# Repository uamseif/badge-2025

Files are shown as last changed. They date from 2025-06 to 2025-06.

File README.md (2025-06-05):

# 🛠️ C1b3rtr4cks Badge 2025

Este repositorio contiene el diseño y firmware de la **badge oficial del evento de ciberseguridad [Cibertracks](https://www.c1b3rtr4cks.es/)**. Este badge está compuesta por **tres placas PCB** ensambladas como un **sandwich**, cada una diseñada en **KiCad**. Además de su función identificativa, su forma permite utilizarla como **portatarjetas físico** para credenciales o tarjetas del evento.

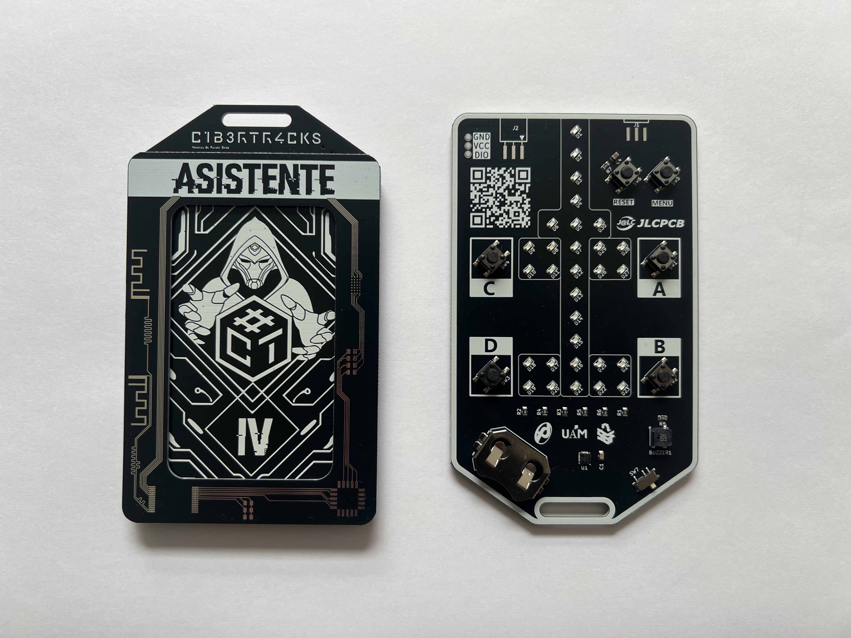
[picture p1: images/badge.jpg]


---

## 🧭 Descripción del Proyecto

- 🔧 **Diseño multicapa:** 3 placas PCB ensambladas en forma de sandwich.
- 🎨 **Diseño personalizado:** Adaptada para representar visualmente la identidad del evento.
- 💾 **Firmware en C:** Corre en un **CH32V003**, un microcontrolador RISC-V.
- 🪪 **Funcionalidad dual:** Badge electrónica + portatarjetas físico.

---

## 🧩 Hardware

La placa está diseñada en tres capas, cada una como un proyecto independiente en **KiCad**:

- **badge2025**: Capa frontal. Incluye LEDs, botones y detalles gráficos del evento.
- **middle_frame**: Elemento mecánico que actua como separador y de retenedor de tarjetas.
- **front_frame**: Capa frontal que extiende el diseño de la placa principal.

Estas capas se ensamblan de forma compacta, resultando en una badge robusta y funcional, apta para colgar con lanyard o sujetar una tarjeta del evento.

---

## 💻 Firmware

El firmware está ubicado en `software` y está desarrollado en **C** usando **PlatformIO**.

Se trata de una serie de minijuegos a los que se puede jugar con otra persona juntando dos placas. 

### 📦 Requisitos

- [PlatformIO](https://platformio.org/)
- Programador compatible con CH32V003 (ej. WCH-LinkE, USB-UART + BOOT0)

## ▶️ ¿Cómo usar la placa?

En la siguiente [página](HOW-TO-USE.md) encontramos instrucciones de como usar la placa y jugar con ella.

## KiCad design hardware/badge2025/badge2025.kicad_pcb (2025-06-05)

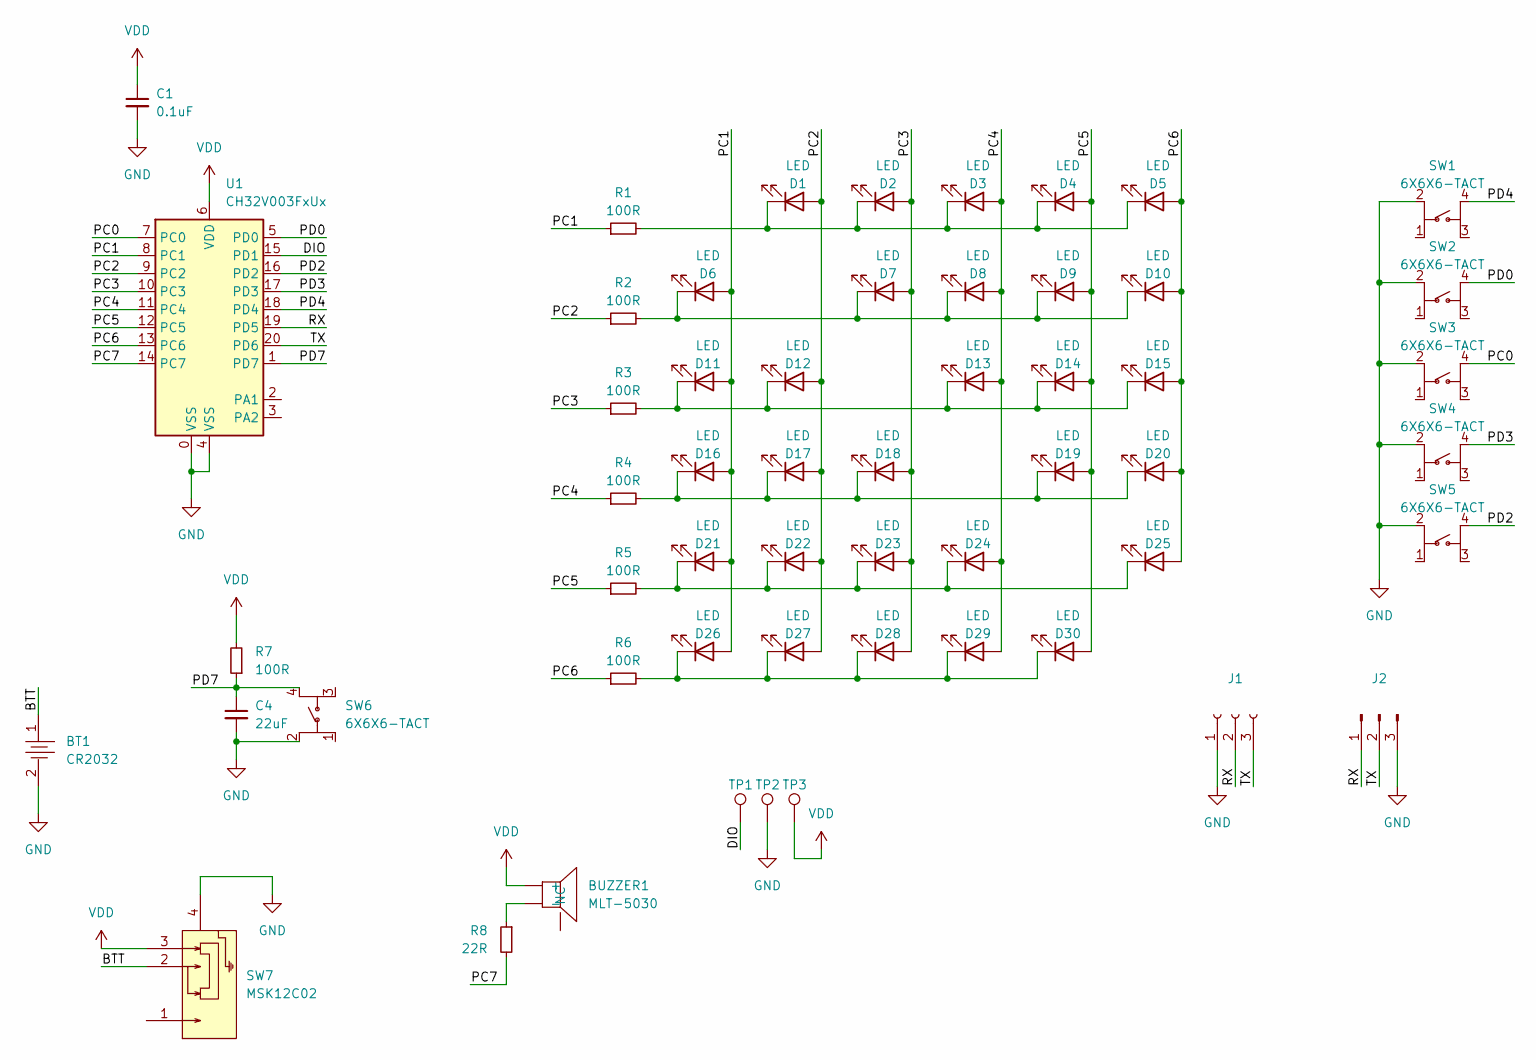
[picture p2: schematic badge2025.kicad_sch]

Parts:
BT1: CR2032; BAT-SMD_MY-2032-08
BUZZER1: MLT-5030; BUZ-SMD_3P-L5.2-W5.2-P3.50-BR
C1: 0.1uF; C_0805_2012Metric
C4: 22uF; C_0805_2012Metric
D1, D2, D3, D4, D5, D6, D7, D8, D9, D10, D11, D12, D13, D14, D15, D16, D17, D18, D19, D20, D21, D22, D23, D24, D25, D26, D27, D28, D29, D30: LED; LED_0805_2012Metric
J1: Conn_01x03_Socket; HDR-SMD_3P-P2.54-H-M
J2: Conn_01x03_Pin; HDR-SMD_3P-P2.54-H-F-L11.5
R1, R2, R3, R4, R5, R6, R7: 100R; R_0805_2012Metric
R8: 22R; R_0805_2012Metric
SW1, SW2, SW3, SW4, SW5, SW6: 6X6X6-TACT; SW-SMD_4P-L6.0-W6.0-P4.50-LS9.2
SW7: MSK12C02; SW-TH_MSK12C02
TP1, TP2, TP3: TestPoint; TestPoint_Pad_D1.5mm
U1: CH32V003FxUx; QFN-20-1EP_3x3mm_P0.4mm_EP1.65x1.65mm

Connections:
/BTT: BT1.1, SW7.2
/DIO: TP1.1, U1.15 (PD1)
/PC0: SW3.4 (D), U1.7 (PC0)
/PC1: D6.2 (A), D11.2 (A), D16.2 (A), D21.2 (A), D26.2 (A), R1.1, U1.8 (PC1)
/PC2: D1.2 (A), D12.2 (A), D17.2 (A), D22.2 (A), D27.2 (A), R2.1, U1.9 (PC2)
/PC3: D2.2 (A), D7.2 (A), D18.2 (A), D23.2 (A), D28.2 (A), R3.1, U1.10 (PC3)
/PC4: D3.2 (A), D8.2 (A), D13.2 (A), D24.2 (A), D29.2 (A), R4.1, U1.11 (PC4)
/PC5: D4.2 (A), D9.2 (A), D14.2 (A), D19.2 (A), D30.2 (A), R5.1, U1.12 (PC5)
/PC6: D5.2 (A), D10.2 (A), D15.2 (A), D20.2 (A), D25.2 (A), R6.1, U1.13 (PC6)
/PC7: R8.2, U1.14 (PC7)
/PD0: SW2.4 (D), U1.5 (PD0)
/PD2: SW5.4 (D), U1.16 (PD2)
/PD3: SW4.4 (D), U1.17 (PD3)
/PD4: SW1.4 (D), U1.18 (PD4)
/PD7: C4.1, R7.1, SW6.4 (D), U1.1 (PD7)
/RX: J1.2, J2.1, U1.19 (PD5)
/TX: J1.3, J2.2, U1.20 (PD6)
/XI: U1.2 (PA1)
/XO: U1.3 (PA2)
GND: BT1.2, C1.2, C4.2, J1.1, J2.3, SW1.2 (B), SW2.2 (B), SW3.2 (B), SW4.2 (B), SW5.2 (B), SW6.2 (B), SW7.4, TP2.1, U1.0 (VSS), U1.4 (VSS)
unnamed: BUZZER1.3 (-), R8.1
unnamed: D1.1 (K), D2.1 (K), D3.1 (K), D4.1 (K), D5.1 (K), R1.2
unnamed: D6.1 (K), D7.1 (K), D8.1 (K), D9.1 (K), D10.1 (K), R2.2
unnamed: D11.1 (K), D12.1 (K), D13.1 (K), D14.1 (K), D15.1 (K), R3.2
unnamed: D16.1 (K), D17.1 (K), D18.1 (K), D19.1 (K), D20.1 (K), R4.2
unnamed: D21.1 (K), D22.1 (K), D23.1 (K), D24.1 (K), D25.1 (K), R5.2
unnamed: D26.1 (K), D27.1 (K), D28.1 (K), D29.1 (K), D30.1 (K), R6.2
VDD: BUZZER1.2 (+), C1.1, R7.2, SW7.3, TP3.1, U1.6 (VDD)

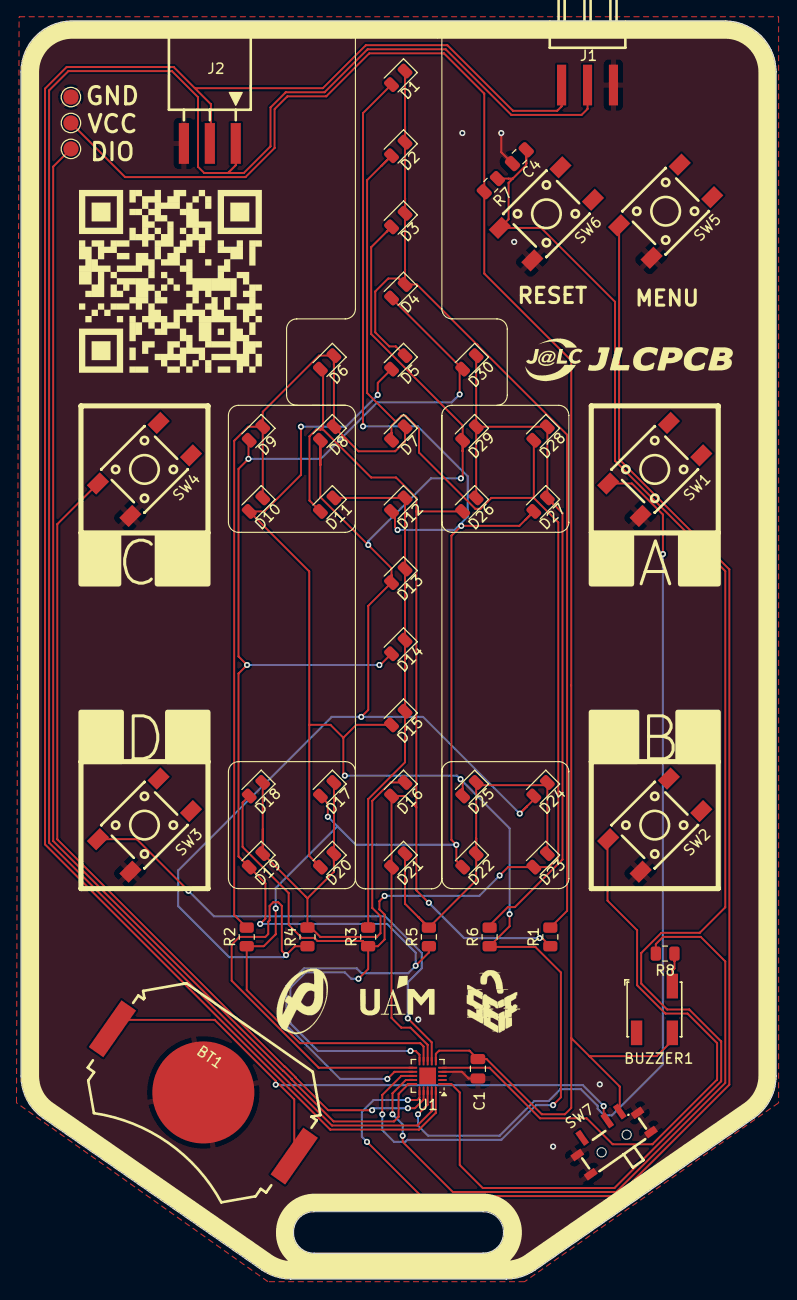
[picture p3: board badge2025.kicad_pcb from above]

Board: 2 copper layers, 74.0 x 123.3 mm, 55 parts (0 on the bottom side), 26 nets.

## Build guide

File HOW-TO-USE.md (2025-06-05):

# 

Este proyecto combina hardware y software en una placa PCB interactiva que permite jugar a tres minijuegos clásicos: **Ping Pong**, **Simon Dice** y **Reflejos**.  
La placa está equipada con botones, LEDs y la capacidad de conectarse con otra para jugar en **modo multijugador**.

A continuación, encontrarás las instrucciones para navegar por el menú principal, seleccionar juegos y comprender la dinámica de cada uno, tanto en modo individual como multijugador.

## Menú Principal

- **Encender la placa**
  Para encender la placa, basca con mover el switch SW7 a la posición de encendido. Acto seguido, la placa entra en modo *salvapantallas*.

- **Salir del modo salvapantallas:**  
  Pulsa cualquiera de los botones **A**, **B**, **C** o **D** para salir del salvapantallas y acceder al menú principal.

- **Indicador visual de selección:**  
  Cuatro LEDs (D1, D2, D3 Y D4) en la placa mostrarán la selección actual en formato binario, facilitando saber qué juego está seleccionado.

- **Seleccionar el juego:**  
  Utiliza los botones **C** y **D** para moverte entre los minijuegos disponibles:
  
  | Juego                                             | D1 D2 D3 D4 |
  | ------------------------------------------------- | ----------- |
  | [Ping Pong](#ping-pong)                           | 0001        |
  | [Simon Dice](#simon-dice)                         | 0010        |
  | [Reflejos](#reflejos)                             | 0011        |
  | [Ping Pong Multijugador](#ping-pong-multijugador) | 0100        |
  | [Reflejos Multijugador](#reflejos-multijugador)   | 0101        |

- **Confirmar selección:**  
  Presiona el botón **B** para iniciar el juego seleccionado.

- **Volver al menú:**
  Pulsa el botón MENU para volver al menú principal desde cualquier juego. 

> :memo: **Nota**:
> 
> - Para jugar en modo multijugador, **dos placas deben conectarse** físicamente entre sí tal como se muestra en la foto 
>   .
> - Uno de los jugadores debe iniciar un juego en **modo multijugador** desde el menú principal para comenzar la partida entre ambas placas.

## Ping Pong

En el juego Ping Pong, la mecánica es sencilla pero requiere buen timing y concentración.

- **Inicio del juego:**  
  Al comenzar, una pelota representada por un LED caerá por la línea central de LEDs.

- **Objetivo:**  
  Debes hacer rebotar la pelota todo el tiempo que puedas, pero recuerda que no puedes dejar que caiga o hacerla rebotar antes de tiempo

- **Cómo hacer rebotar la pelota:**  
  Para hacerla rebotar, pulsa cualquiera de los botones **D** o **B**.  
  **Importante:** La pelota solo rebotará si está encendida en los LEDs naranjas, que corresponden a **D14** y **D15**.

## Simon Dice

Simon Dice es un juego clásico de memoria y atención.

- **Controles y colores:**  
  La placa tiene cuatro grupos de colores, cada uno asociado a un botón:
  
  - **Rojo** — botón **C**
  - **Verde** — botón **D**
  - **Amarillo** — botón **A**
  - **Azul** — botón **B**

- **Dinámica del juego:**  
  La placa iniciará mostrando una secuencia de LEDs encendiéndose en distintos colores.  
  Tu tarea es **replicar la secuencia** pulsando los botones correspondientes en el mismo orden.

- **Progresión:**  
  Cada vez que completes correctamente la secuencia, el juego añadirá un color nuevo al final de la lista y deberás recordarla y repetirla con la nueva adición.

- **Objetivo:**  
  Mantén la concentración y recuerda la secuencia creciente para seguir avanzando y lograr la mayor puntuación posible.

## Reflejos

Reflejos es un juego que pone a prueba tu rapidez y tiempo de reacción.

- **Controles y colores:**  
  Igual que en Simon Dice, cada color está asociado a un botón:
  
  - **Rojo** — botón **C**
  - **Verde** — botón **D**
  - **Amarillo** — botón **A**
  - **Azul** — botón **B**

- **Dinámica del juego:**  
  La placa mostrará un color iluminando el LED correspondiente.  
  Tu objetivo es **pulsar rápidamente el botón asociado a ese color**.

- **Dificultad creciente:**  
  El tiempo para reaccionar irá disminuyendo progresivamente, haciendo que debas estar cada vez más atento y rápido para no perder.

- **Objetivo:**  
  Mantén la concentración y responde rápido para lograr la máxima puntuación posible.

## Ping Pong Multijugador

El modo multijugador de Ping Pong mantiene la misma mecánica que el modo normal, pero con dos jugadores enfrentados.

- **Dinámica:**  
  La pelota rebota entre los dos usuarios, que deberán hacerla rebotar correctamente usando los botones correspondientes.

- **Objetivo:**  
  Cada jugador debe hacer rebotar la pelota en el momento justo.  
  Pierde el jugador que haga rebotar la pelota fuera de tiempo o que deje que caiga sin rebotar.

## Reflejos Multijugador

El modo multijugador de Reflejos se basa en turnos entre dos jugadores.

- **Dinámica:**  
  El jugador que inicia el juego genera un color (LED encendido), y el otro jugador debe pulsar rápidamente el botón correspondiente.  
  Luego, el turno cambia y el siguiente jugador genera un color para que el contrario responda.

- **Objetivo:**  
  Cada jugador debe reaccionar rápido y correctamente al color mostrado por el oponente.  
  El juego continúa alternando turnos, poniendo a prueba los reflejos de ambos jugadores.

## Marcador Final

Al finalizar cualquier juego, la placa muestra un marcador visual que indica tu rendimiento en cada minijuego. Este marcador utiliza los LEDs como contador de aciertos. Si el número de aciertos supera los 10, el contador se reinicia, repitiendo el ciclo hasta llegar al número de aciertos.

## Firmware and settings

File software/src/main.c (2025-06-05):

#include <stdio.h>
#include "ch32v003fun.h"
#include "gpio.h"
#include "multiplayer.h"
#include "pingpong.h"
#include "menu.h"
#include "simon.h"
#include "reflexes.h"


#define LOOP_STATE_MENU 0
#define LOOP_STATE_PINGPONG 1
#define LOOP_STATE_SIMON 2 
#define LOOP_STATE_REACTION 3

uint8_t ledsBuffer[30];
volatile uint32_t systick_millis;
uint8_t loop_state = LOOP_STATE_MENU;
uint8_t multiplayer = MULTIPLAYER_OFF;
uint8_t multiplayer_accepted_game = 0;

void systick_init(void)
{
    // Disable default SysTick behavior
    SysTick->CTLR = 0;

    // Enable the SysTick IRQ
    NVIC_EnableIRQ(SysTicK_IRQn);

    // Set the tick interval
    SysTick->CMP = (FUNCONF_SYSTEM_CORE_CLOCK / 50000) - 1;

    // Start at zero
    SysTick->CNT = 0;

    // Enable SysTick counter, IRQ, HCLK/1
    SysTick->CTLR = SYSTICK_CTLR_STE | SYSTICK_CTLR_STIE | SYSTICK_CTLR_STCLK;
}


// SysTick ISR just counts ticks
__attribute__((interrupt)) void SysTick_Handler(void)
{
    // Move the compare further ahead in time. as a warning, if more than this length of time
    // passes before triggering, you may miss your interrupt.
    SysTick->CMP += (FUNCONF_SYSTEM_CORE_CLOCK / 50000);

    // Clear IRQ
    SysTick->SR = 0;
    systick_millis++;
    led_matrix_run();
}

void return_to_menu() {
    clear_leds();
    loop_state = LOOP_STATE_MENU;
}

void start_ping_pong() {
    loop_state = LOOP_STATE_PINGPONG;
    pingpong_init();
    menu_selection = 0;
}

void start_simon() {
    loop_state = LOOP_STATE_SIMON;
    simon_init();
    menu_selection = 0;
}

void start_reflexes() {
    loop_state = LOOP_STATE_REACTION;
    reaction_init();
    menu_selection = 0;
}

int main() {
    SystemInit();
    Delay_Ms(100);

    // Init systick
    systick_init();

    // Init LED matrix
    led_matrix_init();
    buttons_init();
    gpio_uart_init();

    //pingpong_init();
    menu_init();
    // ReSharper disable once CppDFAEndlessLoop
    while (1)
    {
        switch (loop_state) {
            case LOOP_STATE_MENU:
                menu_run();
                if (menu_selection == 1) {
                    start_ping_pong();
                } else if (menu_selection == 2) {
                    start_simon();
                } else if (menu_selection == 3) {
                    start_reflexes();
                } else if (menu_selection == 4) {
                    start_multiplayer_game(MSG_GAME_PINGPONG);
                    multiplayer = MULTIPLAYER_MASTER;
                    start_ping_pong();
                } else if (menu_selection == 5) {
                    start_multiplayer_game(MSG_GAME_REFLEXES);
                    multiplayer = MULTIPLAYER_MASTER;
                    start_reflexes();;
                }
                break;
            case LOOP_STATE_PINGPONG:
                pingpong_run();
                break;
            case LOOP_STATE_SIMON:
                simon_run();
                break;
            case LOOP_STATE_REACTION:
                reaction_run();
                break;    
            default:
                break;
        }
        process_uart();

        if (multiplayer_accepted_game != 0) {
            multiplayer = MULTIPLAYER_SLAVE;
            switch (multiplayer_accepted_game) {
                case MSG_GAME_PINGPONG:
                    start_ping_pong();
                    break;
                case MSG_GAME_REFLEXES:
                    start_reflexes();
                    break;
                case MSG_GAME_SIMON:
                default: break;
            }
            multiplayer_accepted_game = 0;
        }
    }
}

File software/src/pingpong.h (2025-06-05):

#pragma once
#include "gpio.h"

#define PING_PONG_LEDS 12
#define PING_PONG_STATE_START 0
#define PING_PONG_STATE_GAME 1
#define PING_PONG_STATE_FAIL 2
#define PING_PONG_STATE_WIN  3
#define PING_PONG_STATE_WAIT 4

#define MSG_ACTION_BOUNCE 0
#define MSG_ACTION_MASTER_WIN 1
#define MSG_ACTION_SLAVE_WIN 2

uint8_t leds[] = {1, 2, 3, 4, 5, 7, 12, 13, 14, 15, 16, 21};
int8_t current_led = 0;
static uint32_t pingMillis = 0;
uint8_t speed = 1;
int ms_per_speed = 1000;
uint8_t win_led = 8;
uint8_t direction = 1;
uint8_t current_state = PING_PONG_STATE_START;

uint8_t error_led = 7;
uint8_t success_led = 16;
uint8_t error_leds_count = 4;
uint8_t error_cycle = 0;
uint8_t error_cycles_count = 40;

extern void return_to_menu();
extern uint8_t multiplayer;


static inline void draw_ping_pong() {
    for (uint8_t i = 0; i < PING_PONG_LEDS; i++) {
        leds_buffer[leds[i] - 1] = current_led == i ? 1 : 0;
    }
}

static inline void pingpong_init() {
    clear_leds();
    pingMillis = systick_millis;

    if (multiplayer == MULTIPLAYER_SLAVE) {
        current_state = PING_PONG_STATE_WAIT;
    }
}

static inline void pingpong_error() {
    current_led = 0;
    speed = 1;
    clear_leds();
    current_state = PING_PONG_STATE_FAIL;
}

static inline void pingpong_win() {
    current_led = 0;
    speed = 1;
    clear_leds();
    current_state = PING_PONG_STATE_WIN;
}

static inline void pingpong_success() {
    speed += 1;
    direction = -1;
}

static inline void update_multiplayer() {
    if (multiplayer > 0) {
        const uint8_t pingpong_message[] = { multiplayer == MULTIPLAYER_MASTER ? MSG_ACTION_SLAVE_WIN : MSG_ACTION_MASTER_WIN };
        const uint8_t pingpong_message_length = sizeof(pingpong_message);
        send_game_message(MSG_GAME_PINGPONG, pingpong_message, pingpong_message_length);
    }
}

static inline void pingpong_game() {
    const uint32_t currentMillis = systick_millis;

    if (currentMillis - pingMillis >= MS_TO_TICKS(ms_per_speed / speed)) {

        pingMillis = currentMillis;

        current_led = (int8_t)(current_led + direction);
        if (current_led == PING_PONG_LEDS) {
            pingpong_error();
            update_multiplayer();
        }

        if (current_led < 0) {
            if (multiplayer > 0) {
                direction = 1;
                current_led = -1;
                current_state = PING_PONG_STATE_WAIT;
                clear_leds();

                uint8_t pingpong_message[] = { MSG_ACTION_BOUNCE, speed };
                uint8_t pingpong_message_length = sizeof(pingpong_message);

                send_game_message(MSG_GAME_PINGPONG, pingpong_message, pingpong_message_length);
            } else {
                direction = 1;
                current_led = 1;
            }

        }
    }

    if (button_is_pressed(BUTTON_D) || button_is_pressed(BUTTON_B)) {
        if (current_led >= win_led && current_led <= win_led + 1) {
            pingpong_success();
        } else {
            pingpong_error();
            update_multiplayer();
        }
    }
}

static inline void pingpong_fail_leds() {
    const uint32_t currentMillis = systick_millis;

    if (currentMillis - pingMillis >= MS_TO_TICKS(100)) {
        pingMillis = currentMillis;

        leds_buffer[error_led + current_led] = 0;
        current_led += 1;
        if (current_led >= error_leds_count) {
            current_led = 0;
        }
        leds_buffer[error_led + current_led] = 1;

        error_cycle += 1;
        if (error_cycle >= error_cycles_count) {
            if (multiplayer == MULTIPLAYER_SLAVE) {
                current_state = PING_PONG_STATE_WAIT;
            } else {
                current_state = PING_PONG_STATE_START;
            }
            error_cycle = 0;
            clear_leds();
        }
    }
}

static inline void pingpong_success_leds() {
    const uint32_t currentMillis = systick_millis;

    if (currentMillis - pingMillis >= MS_TO_TICKS(100)) {
        pingMillis = currentMillis;

        leds_buffer[success_led + current_led] = 0;
        current_led += 1;
        if (current_led >= error_leds_count) {
            current_led = 0;
        }
        leds_buffer[success_led + current_led] = 1;

        error_cycle += 1;
        if (error_cycle >= error_cycles_count) {
            current_state = multiplayer == MULTIPLAYER_MASTER ? PING_PONG_STATE_START : PING_PONG_STATE_WAIT;
            error_cycle = 0;
            clear_leds();
        }
    }
}
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

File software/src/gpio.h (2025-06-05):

#pragma once

#include "ch32v003_GPIO_branchless.h"
#include "definitions.h"
#include "lib_uart.h"

#define MS_TO_TICKS(ms) ((ms) * 48)

#define LED_MATRIX_NUM_PINS     6
#define LED_MATRIX_SIZE     (LED_MATRIX_NUM_PINS * (LED_MATRIX_NUM_PINS - 1))
#define BUTTON_COUNT            5

#define PIN_BEEP             PC7

#define PIN_BUTTON_A         PD4
#define PIN_BUTTON_B         PD0
#define PIN_BUTTON_C         PD3
#define PIN_BUTTON_D         PC0
#define PIN_BUTTON_MENU      PD2

#define BUTTON_A             0
#define BUTTON_B             1
#define BUTTON_C             2
#define BUTTON_D             3
#define BUTTON_MENU          4
#define DEBOUNCE_DELAY_MS    2000

#define UART_BUFFER_SIZE 32
uint8_t uart_buffer[UART_BUFFER_SIZE];
size_t uart_bytes_read;

static uint32_t last_millis = 0;

uint8_t leds_buffer[LED_MATRIX_SIZE];
#define BUZZER_BUFFER_SIZE 10
Sound sound_buffer[BUZZER_BUFFER_SIZE];
uint8_t buzzer_head = 0, buzzer_tail = 0, buzzer_count = 0, buzzer_state = 0;
static uint32_t buzzer_millis = 0;

Button buttons[BUTTON_COUNT];

extern volatile uint32_t systick_millis;

int led_positions[LED_MATRIX_SIZE][2] = {
    {PC1, PC2}, // LED 1
    {PC1, PC3}, // LED 2
    {PC1, PC4}, // LED 3
    {PC1, PC5}, // LED 4
    {PC1, PC6}, // LED 5

    {PC2, PC1}, // LED 6
    {PC2, PC3}, // LED 7
    {PC2, PC4}, // LED 8
    {PC2, PC5}, // LED 9
    {PC2, PC6}, // LED 10

    {PC3, PC1}, // LED 11
    {PC3, PC2}, // LED 12
    {PC3, PC4}, // LED 13
    {PC3, PC5}, // LED 14
    {PC3, PC6}, // LED 15

    {PC4, PC1}, // LED 16
    {PC4, PC2}, // LED 17
    {PC4, PC3}, // LED 18
    {PC4, PC5}, // LED 19
    {PC4, PC6}, // LED 20

    {PC5, PC1}, // LED 21
    {PC5, PC2}, // LED 22
    {PC5, PC3}, // LED 23
    {PC5, PC4}, // LED 24
    {PC5, PC6}, // LED 25

    {PC6, PC1}, // LED 26
    {PC6, PC2}, // LED 27
    {PC6, PC3}, // LED 28
    {PC6, PC4}, // LED 29
    {PC6, PC5}, // LED 30
};

static inline void led_matrix_init()
{
    GPIO_port_enable(GPIO_port_C);
}

static inline void led_matrix_run()
{
    static int ledIndex = 0;


    GPIO_pinMode(led_positions[ledIndex][0], GPIO_pinMode_I_floating, GPIO_Speed_10MHz);
    GPIO_pinMode(led_positions[ledIndex][1], GPIO_pinMode_I_floating, GPIO_Speed_10MHz);

    ledIndex++;

    if (ledIndex >= LED_MATRIX_SIZE) {
        ledIndex = 0;
    }

    const uint8_t led = leds_buffer[ledIndex];

    if (led) {
        GPIO_pinMode(led_positions[ledIndex][0], GPIO_pinMode_O_pushPull, GPIO_Speed_10MHz);
        GPIO_pinMode(led_positions[ledIndex][1], GPIO_pinMode_O_pushPull, GPIO_Speed_10MHz);

        GPIO_digitalWrite(led_positions[ledIndex][0], low);
        GPIO_digitalWrite(led_positions[ledIndex][1], high);
    }

}

static inline void clear_leds() {
    for (int i = 0; i < LED_MATRIX_SIZE; i++) {
        leds_buffer[i] = 0;
    }
}

static inline void buzzer_init() {
    GPIO_port_enable(GPIO_port_C);

}

static inline void add_sound(uint32_t frequency, uint32_t duration) {
    if (buzzer_count < BUZZER_BUFFER_SIZE) {
        sound_buffer[buzzer_tail].frequency = frequency;
        sound_buffer[buzzer_tail].duration = duration;
        buzzer_tail = (buzzer_tail + 1) % BUZZER_BUFFER_SIZE;
        buzzer_count++;
    } else {
#ifdef DEBUG
        printf("Buffer lleno, no se puede agregar sonido.\n");
#endif
    }
}


static inline void buzzer_run() {
    const uint32_t currentMillis = systick_millis;
    if (buzzer_count > 0) {
        if (currentMillis - buzzer_millis >= sound_buffer[buzzer_head].frequency) {
            buzzer_state = buzzer_state  == 0 ? 1 : 0;
            buzzer_millis = currentMillis;
            if (buzzer_state == 1) {
                GPIO_pinMode(PIN_BEEP, GPIO_pinMode_O_pushPull, GPIO_Speed_10MHz);
            } else {
                GPIO_pinMode(PIN_BEEP, GPIO_pinMode_I_floating, GPIO_Speed_10MHz);
            }
        }
        sound_buffer[buzzer_head].duration--;

        if (sound_buffer[buzzer_head].duration <= 0) {
            buzzer_head = (buzzer_head + 1) % BUZZER_BUFFER_SIZE;
            buzzer_count--;
        }
    }
}

static inline int button_is_pressed(const uint8_t btn) {
    Button *button = &buttons[btn];
    const int currentState = GPIO_digitalRead(button->pin) == 1;

    uint32_t now = systick_millis;

    if (currentState != button->lastState) {
        button->lastDebounceTime = now;
    }

    if ((now - button->lastDebounceTime) > DEBOUNCE_DELAY_MS) {
        if (currentState != button->debouncedState) {
            button->debouncedState = currentState;

            if (button->debouncedState == 0) {
                button->lastState = currentState;
                return 1;
            }
        }
    }

    button->lastState = currentState;
    return 0;
}
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
